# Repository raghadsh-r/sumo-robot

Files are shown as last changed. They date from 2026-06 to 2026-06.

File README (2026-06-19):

🤖 Sumo Robot Project - 3kg Category
This repository documents the development, logic, and hardware design of our 3kg Mega Sumo Robot, developed as part of our robotics engineering projects.

🏆 Project Achievements
Our team successfully secured 9th place in the MRC Magnetic Mega Sumo 3kg competition, which qualified us for the Global Finals in Greece.

📂 Repository Structure
/body: Contains the hardware design and chassis construction details.

/final_sumo_logic: Contains the core programming and logic for the robot's autonomous behavior.

FINAL_Waslleh_Sumo_3kg_List: Procurement and parts list for the robot.

Schedule: Project timeline and competition preparation phases.

التأهل لليونان: Official qualification documentation.

🛠 Tech Stack
Hardware: Arduino/Microcontrollers, Infrared Sensor Arrays (QTR-8A), Mechanical Switches.

Design & Fabrication: Advanced hardware design, 3D printing (Bambu Studio).

Programming: C++/Arduino Logic.

👥 The Team
This project is a collaborative effort by our robotics team: Raghad Alshrawneh, Renad, Shaza.

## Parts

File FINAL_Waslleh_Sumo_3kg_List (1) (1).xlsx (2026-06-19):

Category | Item | Model / Spec | Qty | Unit Price (JD) | Total (JD) | Weight (g) | Dimensions | Notes | Waslleh Link
Motor | DC Gear Motor | JSUMO Titan 12V 200RPM | 4 | 26 | 104 | 180 | 37x70mm, shaft 6mm | Recommended torque for 3kg class | https://waslleh.com/product/jsumo-titan-dc-gearhead-motor-12v-200-rpm-601/ | Estimated Total | 1043.18
Wheels | Silicone Wheels | JSUMO JS5230 Aluminum – Silicone Wheel Set (52 x 30mm – Pair) | 2 | 32 | 64 | 200 | Diameter 74mm, width ~44mm, bore 6mm | Best grip for Mega Sumo | https://waslleh.com/product/jsumo-js5230-aluminum-silicone-wheel-set-52-x-30mm-pair/ | Remaining | #REF!
Driver | Motor Driver | Double BTS7960 43A H-Bridge | 2 | 11.41 | 22.82 | 55 | Module ~70x50mm | Powerful driver for two motors | https://waslleh.com/product/double-bts7960-43a-h-bridge/
Sensor | Line Sensor | JSUMO Micro Line Sensor ML1 | 4 | 2.3 | 9.2 | 2 | 12.7x7.6mm | comes in 2 | https://waslleh.com/product/jsumo-micro-line-sensor-ml1/
Sensor | IR Sensor | JSUMO JS40F Digital Distance Sensor | 4 | 12.66 | 50.64 | 7 | 29.5x13mm | range 10cm - 80cm | https://waslleh.com/product/jsumo-js40f-digital-distance-sensor/
Battery | Power Source | TCBWORTH Lipo Battery 3s 11.1v – 3000mAh 60C XT60 | 1 | 40 | 40 | 230 | ~103x34x22mm | Official recommended power type | https://waslleh.com/product/tcbworth-lipo-battery-3s-11-1v-3000mah-60c-xt60/
Wiring | Power Wire | 16 AWG Silicone Wire | 1 | 5 | 5 | 50 | Red/Black set | For battery and motors | https://waslleh.com/product-category/electronics/wires-cables/
Wiring | Signal Wire | 22-26 AWG wires | 1 | 4 | 4 | 30 | Dupont/JST | For sensors & Arduino | https://waslleh.com/product-category/electronics/wires-cables/
Connectors | XT60 Set | XT60 Male/Female pair | 1 | 2.93 | 2.93 | 15 | Standard battery connector | Matches LiPo battery | https://waslleh.com/product/xt60-pair-connector/
Mechanical | Fasteners | M3 screw & nut kit | 1 | 6 | 6 | 120 | Assorted lengths
micro controller | arduino | nano | 1 | 6 | 6 |  |  |  | https://waslleh.com/product/arduino-nano-original/
sheild | nano sheild | ezz mnasrah | 1 | 20 | 20 |  |  |  | https://waslleh.com/product/jsumo-hss-sumo-robot-blade-no2/
blade | blade | JSUMO HSS Sumo Robot Blade No:2 | 1 | 42 | 42
magnatic | magnatic | magnatic | 10 | 1 | 10 | تقريبا
design | design | design | 1 | 60 | 60 | تقريبا
softwer and hardwer | softwer and hardwer | softwer and hardwer | 1 | 60 | 60 | تقريبا
3d printing | 3d printing | 3d printing | 1 | 15 | 15 | تقريبا
 |  |  |  |  | 521.59

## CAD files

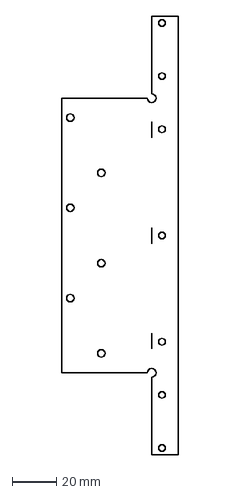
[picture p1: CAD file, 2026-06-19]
body/Flat pattern - sh3.DXF
52.6 x 198.0 mm

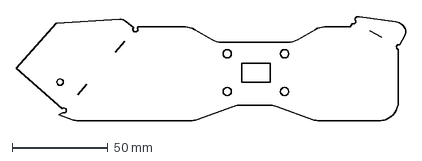
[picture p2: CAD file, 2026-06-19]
body/Flat pattern - sh1.DXF
203.6 x 54.6 mm

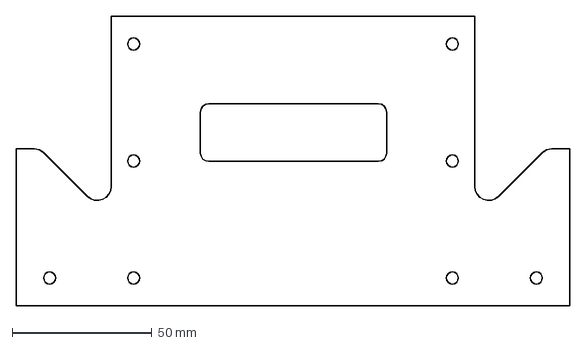
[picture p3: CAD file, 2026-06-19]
body/Flat pattern - sh2.DXF
198.0 x 103.6 mm

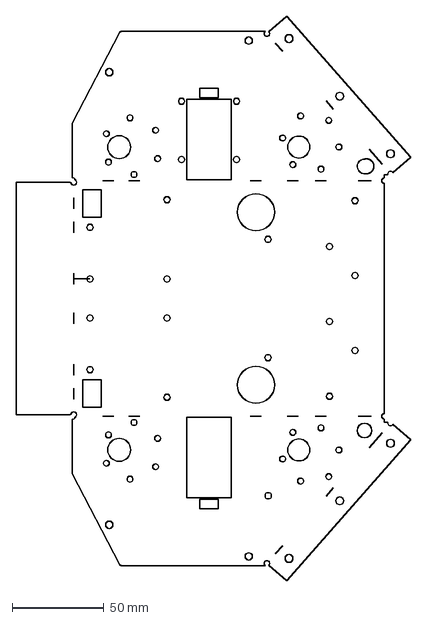
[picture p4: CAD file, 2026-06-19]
body/Flat pattern - sh4.DXF
214.7 x 307.4 mm

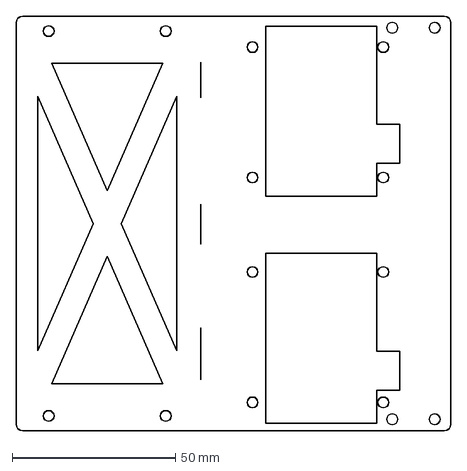
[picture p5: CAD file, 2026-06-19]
body/Flat pattern - sh5.DXF
133.3 x 127.0 mm

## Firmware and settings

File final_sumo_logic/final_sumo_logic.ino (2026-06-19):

#define IR_mid A3
#define IR_midL A2
#define IR_midR A1
#define IR_left A0
#define IR_right 8

#define LEFT_RPWM 10
#define LEFT_LPWM 9
#define RIGHT_RPWM 5
#define RIGHT_LPWM 3

#define line_frontL 2
#define line_frontR 4
#define line_backL 12
#define line_backR 11

const int START_PIN = 7; 

bool robotRunning = false;
bool lastButtonState = HIGH;   // لأننا نستخدم INPUT_PULLUP

void setup() {

  pinMode(IR_mid,INPUT);
  pinMode(IR_midR,INPUT);
  pinMode(IR_midL,INPUT);
  pinMode(IR_left,INPUT);
  pinMode(IR_right,INPUT);

  pinMode(LEFT_RPWM, OUTPUT);
  pinMode(LEFT_LPWM, OUTPUT);

  pinMode(RIGHT_RPWM, OUTPUT);
  pinMode(RIGHT_LPWM, OUTPUT);
  
  pinMode(line_frontL,INPUT);
  pinMode(line_frontR,INPUT);
  pinMode(line_backL,INPUT);
  pinMode(line_backR,INPUT);

  pinMode(START_PIN, INPUT);

  Serial.begin(9600);
}

void loop() {

  // قراءة زر التشغيل
  bool currentButtonState = digitalRead(START_PIN);

  // عند الضغط (ينزل من HIGH إلى LOW)
  if(currentButtonState == LOW && lastButtonState == HIGH){
    robotRunning = !robotRunning;   // قلب الحالة

    if(robotRunning){
      Serial.println("Robot ON");
    }else{
      Serial.println("Robot OFF");
    }

    delay(250); // debounce
  }

  lastButtonState = currentButtonState;

  // اذا الروبوت مطفي
  if(!robotRunning){
    stopMotors();
    return;
  }

  // قراءات الحساسات
  int readIR_mid=digitalRead(IR_mid);
  int readIR_midL=digitalRead(IR_midL);
  int readIR_midR=digitalRead(IR_midR);
  int readIR_Right=digitalRead(IR_right);
  int readIR_left=digitalRead(IR_left);

  int readline_frontL=digitalRead(line_frontL);
  int readline_frontR=digitalRead(line_frontR);
  int readline_backL=digitalRead(line_backL);
  int readline_backR=digitalRead(line_backR);

  // حماية الخط الأبيض أولاً
  if(readline_frontR == 0 && readline_frontL == 0){
    backward();
    delay(500);
    right();
    delay(500);
  }
  else if(readline_frontR == 0){
    backward();
    delay(300);
    left();
    delay(400);
  }
  else if(readline_backL == 0){
    forward();
  }

  // هجوم وتتبع
  else if(readIR_mid == HIGH){
    attack();
  }
  else if(readIR_midL == HIGH || readIR_left == HIGH){
    left();
  }
  else if(readIR_Right == HIGH || readIR_midR == HIGH){
    right();
  }
}

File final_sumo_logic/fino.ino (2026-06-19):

void stopMotors() {
  analogWrite(LEFT_RPWM, 0);
  analogWrite(LEFT_LPWM, 0);
  analogWrite(RIGHT_RPWM, 0);
  analogWrite(RIGHT_LPWM, 0);
}

void left() {
  analogWrite(LEFT_RPWM, 200);
  analogWrite(LEFT_LPWM, 0);

  analogWrite(RIGHT_RPWM, 200);
  analogWrite(RIGHT_LPWM, 0);
}

void right() {
  analogWrite(LEFT_RPWM, 0);
  analogWrite(LEFT_LPWM, 200);

  analogWrite(RIGHT_RPWM, 0);
  analogWrite(RIGHT_LPWM, 200);
}

void forward() {
  analogWrite(LEFT_RPWM, 0);
  analogWrite(LEFT_LPWM, 200);

  analogWrite(RIGHT_RPWM, 200);
  analogWrite(RIGHT_LPWM, 0);
}

void backward () {
  analogWrite(LEFT_RPWM, 200);
  analogWrite(LEFT_LPWM, 0);

  analogWrite(RIGHT_RPWM, 0);
  analogWrite(RIGHT_LPWM, 200);
}
void attack() {
  analogWrite(LEFT_RPWM, 0);
  analogWrite(LEFT_LPWM, 255);

  analogWrite(RIGHT_RPWM, 255);
  analogWrite(RIGHT_LPWM, 0);
}
